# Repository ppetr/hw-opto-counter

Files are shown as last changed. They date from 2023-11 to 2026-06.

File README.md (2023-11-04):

# Universal IR optical, directional proximity detector/counter with TWI (I²C) interface

_*Disclaimer:* This is not an officially supported Google product._

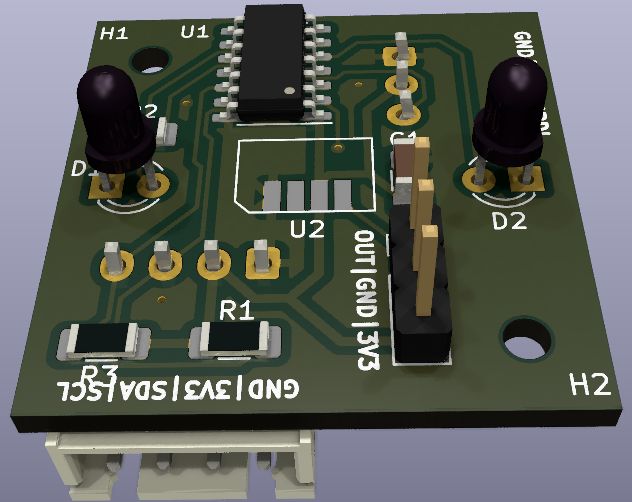
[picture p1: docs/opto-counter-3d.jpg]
3D model of the board


The board uses two IR LEDs with a modulated signal (both either 38KHz or 56KHz,
depending on the receiver type) whose light reflects off objects in front of
the device into an IR receiver.

Using two LEDs allows to determine an approximate position (or direction of
movement) of an object in one dimension. Modulating the signal significantly
reduces interference from natural IR light sources.

The microcontroller
([ATtiny3224](https://www.microchip.com/en-us/product/attiny3224)) varies the
signal strength to compute the strength of the reflected signal using the
[binary search
algorithm](https://en.wikipedia.org/wiki/Binary_search_algorithm).

The measured values are made available through I²C (subordinate).

## Event counter

In addition to reporting current values of reflections from both LEDs, the
microcontroller also counts the number of times the reflection quickly changes
(which we call "events"). These events are defined using two parameters:

- [Exponential moving
  average](https://en.wikipedia.org/wiki/Exponential_smoothing) smoothing
  factor ("half-life"), which computes the baseline signal to compare against.
  The default value is half-life of 10s.
- Delta factor \[0..1\]. An event is triggered when the signal differs more
  than the delta factor from its exponential moving average.

There are the following event types that are counted independently:

1. Signal reflected from LED1 crosses the delta boundary and returns while
   LED2's signal remained within.
   ```
   LED1:  ___|‾‾‾|___
   LED2:  ___________
   ```
2. Similarly the other way around.
3. LED1's signal crossed outside the delta boundary followed by LED2's signal
   crossing outside. This captures the situation when an object is moving in
   the direction LED1->LED2.
   ```
   LED1:  __|‾‾‾|____
   LED2:  ____|‾‾‾|__
   ```
4. Similarly the other way around.

## Status

Development of a prototype.

## Contributions

Please see [Code of Conduct](docs/code-of-conduct.md) and [Contributing](docs/contributing.md).

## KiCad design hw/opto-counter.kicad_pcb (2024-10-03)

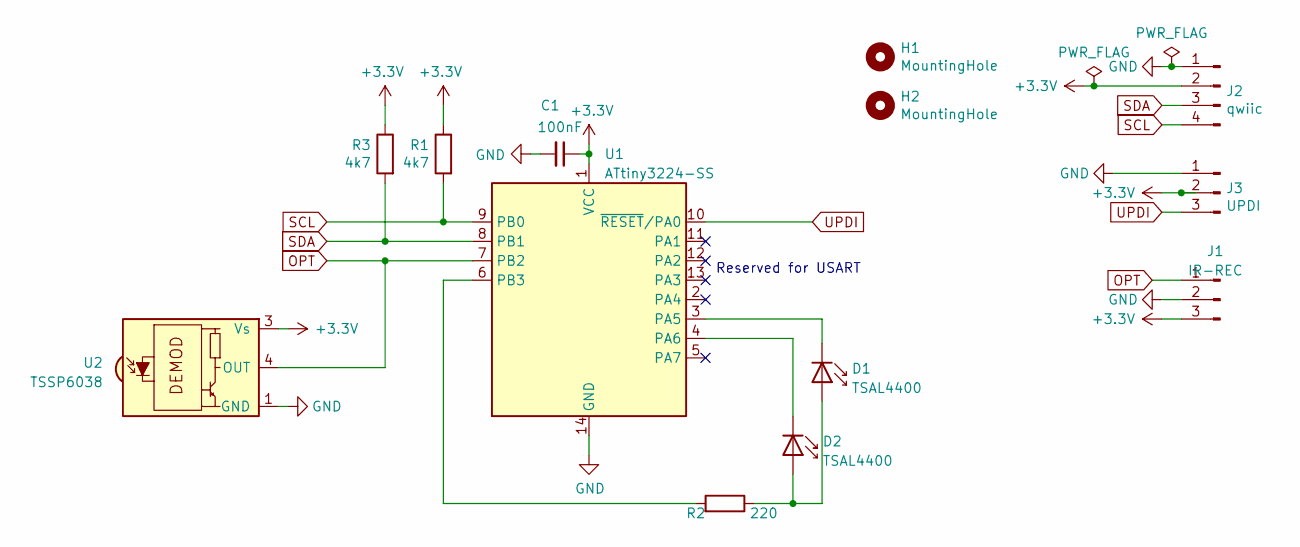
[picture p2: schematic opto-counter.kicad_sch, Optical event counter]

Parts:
C1: 100nF; C_1206_3216Metric_Pad1.33x1.80mm_HandSolder
D1, D2: TSAL4400; LED_D3.0mm_IRBlack
H1, H2: MountingHole; MountingHole_2.2mm_M2
J1: IR-REC; PinHeader_1x03_P2.54mm_Vertical
J2: qwiic; JST_XH_S4B-XH-A_1x04_P2.50mm_Horizontal
J3: UPDI; JST_XH_S3B-XH-A_1x03_P2.50mm_Horizontal
R1, R3: 4k7; R_1206_3216Metric_Pad1.30x1.75mm_HandSolder
R2: 220; R_1206_3216Metric_Pad1.30x1.75mm_HandSolder
U1: ATtiny3224-SS; SOIC-14_3.9x8.7mm_P1.27mm
U2: TSSP6038; TSS60xx

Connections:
+3V3: C1.1, J1.3, J2.2, J3.2, R1.1, R3.1, U1.1 (VCC), U2.3 (Vs)
GND: C1.2, J1.2, J2.1, J3.1, U1.14 (GND), U2.1 (GND)
unnamed: D1.2 (A), D2.2 (A), R2.1
unnamed: D1.1 (K), U1.3 (PA5)
unnamed: D2.1 (K), U1.4 (PA6)
unnamed: R2.2, U1.6 (PB3)
OPT: J1.1, U1.7 (PB2), U2.4 (OUT)
SCL: J2.4, R1.2, U1.9 (PB0)
SDA: J2.3, R3.2, U1.8 (PB1)
UPDI: J3.3, U1.10 (~RESET/PA0)

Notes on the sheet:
Reserved for USART

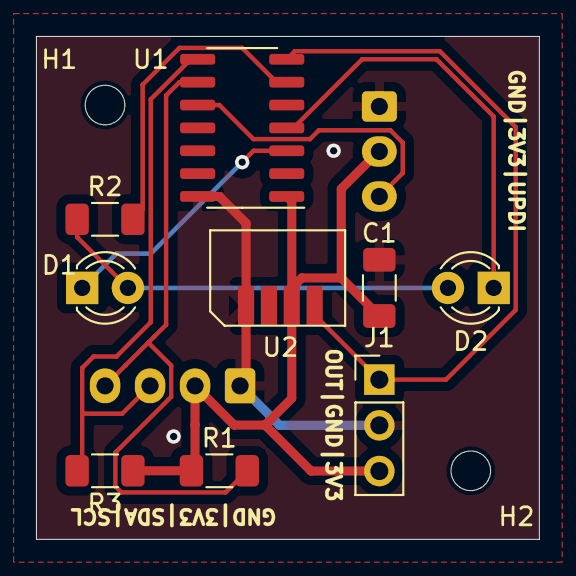
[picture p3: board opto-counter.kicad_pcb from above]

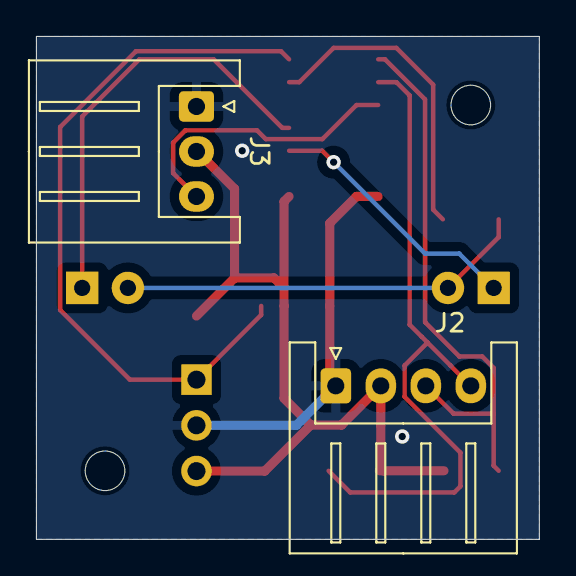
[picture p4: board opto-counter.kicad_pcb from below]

Board: 2 copper layers, 27.9 x 27.9 mm, 13 parts (2 on the bottom side), 10 nets.

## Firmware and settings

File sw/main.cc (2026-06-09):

// Copyright 2023 Google LLC
//
// Licensed under the Apache License, Version 2.0 (the "License");
// you may not use this file except in compliance with the License.
// You may obtain a copy of the License at
//
//     https://www.apache.org/licenses/LICENSE-2.0
//
// Unless required by applicable law or agreed to in writing, software
// distributed under the License is distributed on an "AS IS" BASIS,
// WITHOUT WARRANTIES OR CONDITIONS OF ANY KIND, either express or implied.
// See the License for the specific language governing permissions and
// limitations under the License.

extern "C" {

#include <avr/io.h>
#include <avr/signature.h>
#include <avr/sleep.h>
#include <stdint.h>
#include <stdlib.h>
#include <util/atomic.h>

}  // extern "C"

#include "timer.h"
#include "twi.h"
#include "twi_smbus.h"

constexpr uint8_t kTwiAddress =
    18;  // Randomly generated - https://xkcd.com/221/

class Sleep {
 public:
  explicit Sleep(SLPCTRL_SMODE_enum mode) {
    set_sleep_mode(mode & SLPCTRL_SMODE_gm);
    sleep_enable();
  }
  ~Sleep() { sleep_disable(); }

  void Start() {
    NONATOMIC_BLOCK(NONATOMIC_RESTORESTATE) { sleep_mode(); };
  }
};

struct InputPin {
  InputPin(PORT_t& port_, register8_t bitmask_)
      : port(port_.IN), bitmask(bitmask_) {
    port_.DIRCLR = bitmask;
  }

  bool Read() const { return port & bitmask; }

  const register8_t& port;
  register8_t bitmask;
};

struct Registers {
 public:
  void Snapshot() {}
  bool HasRegister(uint8_t reg) const { return ReadWord(reg).has_value(); }
  optional<int16_t> ReadWord(uint8_t reg) const {
    switch (reg) {
      case 0:
        return led1.fraction_bits;
      case 1:
        return led2.fraction_bits;
      default:
        return {};
    }
  }

  FixedPointFraction<int16_t, 15> led1 = 0;
  FixedPointFraction<int16_t, 15> led2 = 0;
};

using TwiRegisters = TwiClient<SMBusClient<Registers&>>;

class BinarySearch {
 public:
  using value_type = FixedPointFraction<int_fast16_t, 8>;
  constexpr static value_type kNotReady = value_type{-1};

  BinarySearch(TCB0Delay& delay, TCA0_PWM& pwm, InputPin input)
      : delay_(delay),
        pwm_(pwm),
        input_(input),
        lower_(0),
        upper_(value_type(1.0f).fraction_bits - 1) {
    SetPwm();
  }

  // Returns the measured return value in [0..1], or a negative value if not
  // available yet.
  value_type OnInterrupt() {
    if (upper_ == lower_) {
      return value_type(lower_);
    }
    if (delay_.HasTriggered()) {
      if (input_.Read()) {
        lower_ = middle();
      } else {
        upper_ = middle() - 1;
      }
      SetPwm();
    }
    return kNotReady;
  }

 private:
  void SetPwm() {
    // Divide by 2 so that the maximum value for PWM is 0.5 - at which
    // the signal at the base frequency is the strongest.
    pwm_.SetDutyCycle(value_type{middle()}.ShiftRight<1>());
    delay_.Start();
  }

  // As long as `upper_ > lower_`, the result is always `> _lower`.
  value_type::value_type middle() const { return (lower_ + upper_ + 1) / 2; }

  TCB0Delay& delay_;
  TCA0_PWM& pwm_;
  InputPin input_;
  // A value at [lower_] is known to be 0.
  value_type::value_type lower_;
  // A value at [upper_ + 1] is known to be 1.
  // It is assumed that [256] is always 1.
  value_type::value_type upper_;
};

BinarySearch::value_type BinarySearchLoop(TCA0_PWM& pwm, TCB0Delay& delay,
                                          TwiRegisters& twi, Sleep& sleep,
                                          InputPin opt_in) {
  BinarySearch search(delay, pwm, opt_in);
  BinarySearch::value_type signal(0);
  twi.OnInterrupt();  // Process any pending TWI before the first sleep.
  while ((signal = search.OnInterrupt()) == search.kNotReady) {
    sleep.Start();
    twi.OnInterrupt();
  }
  return signal;
}

constexpr const TCA0_PWM::Config kLedPwmFreq(1.0);

int main(void) {
  Sleep sleep(SLPCTRL_SMODE_IDLE_gc);
  Registers regs;
  TwiRegisters twi(kTwiAddress, SMBusClient<Registers&>(regs));
  // Enable output for pins that provide GND to LEDs.
  // Invert so that a logical 1 turns the LED on (GND).
  PORTA.DIRSET = PIN5_bm | PIN6_bm;
  PORTA.PIN5CTRL = PORT_INVEN_bm;
  PORTA.PIN6CTRL = PORT_INVEN_bm;
  // Optical sensor input pin (inverted).
  const InputPin kOptIn(PORTB, PIN2_bm);
  PORTB.PIN2CTRL = PORT_INVEN_bm;
  // Enable the TCA0 PB3 pin (WO0 alternate)
  PORTB.DIRSET = PIN3_bm;
  TCA0_PWM pwm(kLedPwmFreq);
  EVSYS.CHANNEL0 = EVSYS_CHANNEL0_TCA0_CMP0_LCMP0_gc;

  TCB0Delay delay(4, EVSYS_USER_CHANNEL0_gc);
  // Enable global interrupts to allow hardware peripheral events to act as a
  // wake-up signal for the Sleep Controller. Since the ISRs are optimized as
  // `EMPTY_INTERRUPT` (immediate RETI), no application logic executes inside
  // the interrupts; instead, the wake-up triggers the main cooperative loop to
  // poll and process the hardware flags via `OnInterrupt()` methods.
  sei();
  while (true) {
    PORTA.OUTCLR = PIN6_bm;
    PORTA.OUTSET = PIN5_bm;
    regs.led1 = BinarySearchLoop(pwm, delay, twi, sleep, kOptIn).Convert();
    PORTA.OUTCLR = PIN5_bm;
    PORTA.OUTSET = PIN6_bm;
    regs.led2 = BinarySearchLoop(pwm, delay, twi, sleep, kOptIn).Convert();
  };
  EVSYS.CHANNEL0 = EVSYS_CHANNEL0_OFF_gc;
}

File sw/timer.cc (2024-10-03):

// Copyright 2023 Google LLC
//
// Licensed under the Apache License, Version 2.0 (the "License");
// you may not use this file except in compliance with the License.
// You may obtain a copy of the License at
//
//     https://www.apache.org/licenses/LICENSE-2.0
//
// Unless required by applicable law or agreed to in writing, software
// distributed under the License is distributed on an "AS IS" BASIS,
// WITHOUT WARRANTIES OR CONDITIONS OF ANY KIND, either express or implied.
// See the License for the specific language governing permissions and
// limitations under the License.

#include "timer.h"

extern "C" {

#include <avr/interrupt.h>
#include <avr/io.h>
#include <stdint.h>

}  // extern "C"

constexpr float TCA0_PWM::Config::kClkSelFreq[];

TCA0_PWM::TCA0_PWM(Config freq) {
  // See Section 21.5.1 in the manual.
  PORTMUX.TCAROUTEA = PORTMUX_TCA00_ALT1_gc;
  TCA0.SINGLE.PER = freq.per;
  TCA0.SINGLE.CMP0 = 0;  // Duty cycle.
  TCA0.SINGLE.CTRLB = TCA_SINGLE_WGMODE_SINGLESLOPE_gc | TCA_SINGLE_CMP0EN_bm;
  TCA0.SINGLE.CTRLD = 0;
  TCA0.SINGLE.EVCTRL = 0;
  TCA0.SINGLE.INTCTRL = 0;
  // Enable last.
  TCA0.SINGLE.CTRLA =
      ((freq.clkSel << TCA_SINGLE_CLKSEL_gp) & TCA_SINGLE_CLKSEL_gm) |
      TCA_SINGLE_ENABLE_bm;
}

TCA0_PWM::~TCA0_PWM() {
  TCA0.SINGLE.CTRLA = 0;  // Disable completely.
}

TCB0Delay::TCB0Delay(uint16_t count, EVSYS_USER_t input_channel,
                     EVSYS_USER_t helper_channel)
    : trigger_event_(static_cast<EVSYS_SWEVENTA_t>(
          1 << (helper_channel - EVSYS_USER_CHANNEL0_gc + EVSYS_SWEVENTA_gp))),
      count_(count - 1) {
  EVSYS.USERTCB0COUNT = input_channel;
  EVSYS.USERTCB0CAPT = helper_channel;
  // See Section 22.3.3.1.7 in the manual.
  TCB0.EVCTRL = TCB_CAPTEI_bm;
  TCB0.CTRLB = TCB_CNTMODE_SINGLE_gc;
  TCB0.INTCTRL = TCB_CAPT_bm;
  TCB0.CCMP = count_;
  TCB0.CNT = count_;  // Prevent the counter from starting immediately.
  TCB0.CTRLA = TCB_ENABLE_bm | TCB_CLKSEL_EVENT_gc;  // Enable last.
}
TCB0Delay::~TCB0Delay() {
  TCB0.CTRLA = 0;  // Disable.
  TCB0.EVCTRL = 0;
  EVSYS.USERTCB0COUNT = EVSYS_USER_OFF_gc;
}

EMPTY_INTERRUPT(TCB0_INT_vect);

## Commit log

2023-10-22 Initial (untested) prototype
    [opto-counter.kicad_pcb, opto-counter.kicad_sch, opto-counter.sch]
2023-10-30 Remove temporary library `opto-counter-rescue`
    Also add forgotten `fp-lib-table` and small changes to the PCB.
    [opto-counter.kicad_pcb]
2023-10-30 Old gerbers files for archiving
    [opto-counter-B_Cu.gbr, opto-counter-B_Mask.gbr, opto-counter-B_Paste.gbr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]
2023-10-30 Small improvements and fixes in the PCB, generated new gerbers files
    [opto-counter-B_Cu.gbl, opto-counter-B_Cu.gbr, opto-counter-B_Mask.gbr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]
2023-11-03 Use ATtiny1614-SS as the mCPU
    Actually, we're targetting to ATtiny3224, which should be pin
    compatible.
    [opto-counter.kicad_pcb, opto-counter.kicad_sch]
2023-11-03 Move the hardware design to `hw` and add a skeleton of the C software to `sw`
    [opto-counter.kicad_pcb, opto-counter.kicad_sch, opto-counter.sch]
2023-11-04 Remove gerbers and files that have been moved to `hw/`
    Update .gitignore
    [opto-counter-B_Cu.gbl, opto-counter-B_Mask.gbs, opto-counter-B_Paste.gbp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]
2023-11-04 Use ATtiny3224 as the mCPU in the schematic
    [opto-counter.kicad_pcb, opto-counter.kicad_sch]
2023-11-04 Add a footprint for TSSP60xx
    https://www.vishay.com/docs/82868/tssp960.pdf
    [opto-counter.kicad_pcb]
2023-11-24 Configure the TCA0 to emit a test PWM signal.
2023-11-25 Fix the schematic to connect the led to the PB0 (WO0) PWM output of TCA
    [opto-counter.kicad_pcb, opto-counter.kicad_sch]
2023-11-27 Count a given number of pulses from TCA0 using TCB0
    This will allow waiting for the optical receiver a given number of PWM
    wave cycles.
2023-11-27 Add a helper type that represents a fixed point floating point number
    Also a few minor clean-ups.
    [main.cc]
2023-11-28 Move the TCA0 and TCB0 code (the timers) to a separate module
    For some reasons the compilation breaks and `clkSel` becomes a higher
    value than expected (most likely 7 instead of 5). But the CC options to
    optimize the full final binary prevent that again.
    [main.cc, timer.cc]
2023-11-30 Implement a binary search algorithm feeding the PWM duty cycle
    The algorithm returns a value at which value an input pin changes its
    value.
2023-11-30 Add missing copyright headers
    [timer.cc]
2023-12-02 Add an unfinished TWI implementation
    It currently replies correctly only on the first read. Subsequent reads
    return garbled data.
    It's necessary to switch the TCA0 output pins so that the TWI0 ones
    become available.
    [main.cc, timer.cc]
2023-12-02 Working implemention of TWI
    The problem with the previous code was caused by checking the `RXACK`
    flag. The protocol doesn't require that and rather the flag can be set
    to NACK by previous, correct communication.
    [main.cc]
2023-12-02 Change the mCPU pins to match TWI
    [opto-counter.kicad_sch]
2023-12-03 Separate the implementation of a `TwiClient` from the mCPU's state machine
    `TwiClient` now receives a class that needs to implement methods that
    are called at various stages of communication.
2023-12-04 Use `FixedPointFraction` for values returned from `BinarySearch`
    [main.cc]
2023-12-04 Update the PCB with the new pin assignments
    [opto-counter.kicad_pcb]
2023-12-04 Implement the main functionality - measuring taken from both LEDs alternately
2023-12-05 Add a conversion function between different `FixedPointFraction` types
    [main.cc]
2023-12-06 Automatically convert to higher-precision `FixedPrecisionFraction`s
    [main.cc]
2023-12-06 Add auto-confersion of `FixedPointFraction` that with a static shift
    [main.cc]
2023-12-08 Small improvements of the PCB before producing prototype v2
    [opto-counter.kicad_pcb]
2024-10-03 Some more work on fixing the PCB
    [opto-counter.kicad_pcb]
2024-10-03 Properly reset the single-shot timer upon (re)starting
    [timer.cc]
2026-06-09 Enable interrupts in `main` so that they can wake up the Sleep Controller
    Also make sure `OnInterrupt` calls process all pending events, not just
    one.
    See https://gemini.google.com/share/3b2ed1abc276
